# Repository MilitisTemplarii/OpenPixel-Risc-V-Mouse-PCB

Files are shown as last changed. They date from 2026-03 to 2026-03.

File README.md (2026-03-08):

# OpenPixel-Risc-V-Mouse-PCB
Risc-V (CH32V305) based PCB for high-end gaming mouse
0001-0140-ezgif com-optimize
RiscV_pcb_render
RiscV_pcb2_render

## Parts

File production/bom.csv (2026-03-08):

Designator | Footprint | Quantity | Value | LCSC Part #
BOOT1, SW_DPI1 | SW_SPST_TL3342 | 2 | SW_SPST
C1 | 0805 | 1 | 470pF
C10, C12, C9 | 0805 | 3 | 10uF
C11, C13, C15, C16, C17, C18, C19, C20, C22, C6, C7, C8 | 0805 | 12 | 100nF
C14, C21, C5 | 0805 | 3 | 22uF
C2 | 0805 | 1 | 2.2uF
C3, C4 | 0805 | 2 | 1uF
J1 | PinHeader_1x04_P2.00mm_Vertical | 1 | Conn_01x04_Pin
LED_DPI1 | LED_RGB_1210 | 1 | LED_BGRK
PAW3395 | PAW3395_LGA16_fixed | 1 | S1
POLLING1 | SSSS213202_AAL | 1 | SSSS213202
R4 | 0805 | 1 | 5,6K
R5 | 0805 | 1 | 100
R6 | 0805 | 1 | 330
R7 | 0805 | 1 | 220
R8 | 0805 | 1 | 10K
R9 | 0805 | 1 | 1K
RST1 | SW_SPST_EVQP7C | 1 | SW_SPST
SW_LAT1 | JST_SH_SM03B-SRSS-TB_1x03-1MP_P1.00mm_Horizontal | 1 | Conn_01x03_Pin
SW_LEFT1, SW_RGTH1, SW_WHEEL1 | SW_D2FC_OMR | 3 | SW_SPDT_321
U1 | SOT-23-5 | 1 | TLV70019_SOT23-5
U2 | SOT-23-5 | 1 | MIC5219-3.3YM5
U3 | LQFP-64_10x10mm_P0.5mm | 1 | CH32V30xRxTx
U4, U5, U6 | Texas_DRT-3 | 3 | TPD2EUSB30
USB1 | JST_PH_S5B-PH-K_1x05_P2.00mm_Horizontal | 1 | Conn_01x05_Pin
WHEEL_ENCODER1 | Encoder_Kailh_Wheel_3Pin | 1 | RotaryEncoder
Y1 | Oscillator_SMD_SeikoEpson_SG210-4Pin_2.5x2.0mm | 1 | 8MHZ_CMOS

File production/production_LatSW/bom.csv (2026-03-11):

Designator | Footprint | Quantity | Value | LCSC Part #
J1 | PinHeader_1x03_P1.00mm_Vertical | 1 | Conn_01x03
SW1, SW2 | SW_D2FC_OMR | 2 | D2FC-F-7N100M

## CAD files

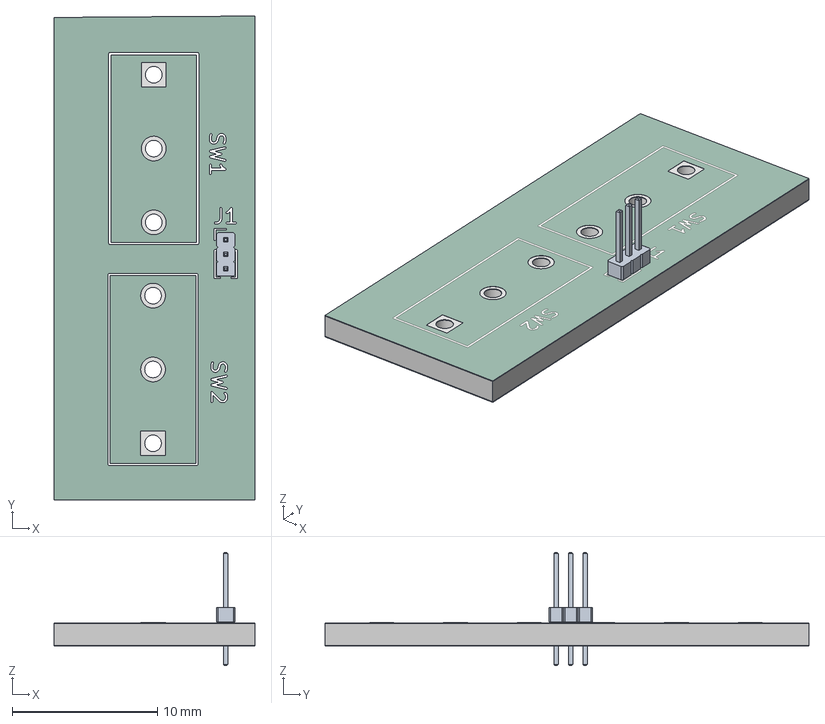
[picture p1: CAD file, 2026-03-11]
KiCad/RiscV_Mouse_LatSW.step
13.8 x 33.3 x 7.80 mm
PinHeader_1x03_P1.00mm_Vertical
RiscV_Mouse_LatSW_copper
RiscV_Mouse_LatSW_pad
RiscV_Mouse_LatSW_silkscreen
RiscV_Mouse_LatSW_soldermask x 2
RiscV_Mouse_LatSW_PCB

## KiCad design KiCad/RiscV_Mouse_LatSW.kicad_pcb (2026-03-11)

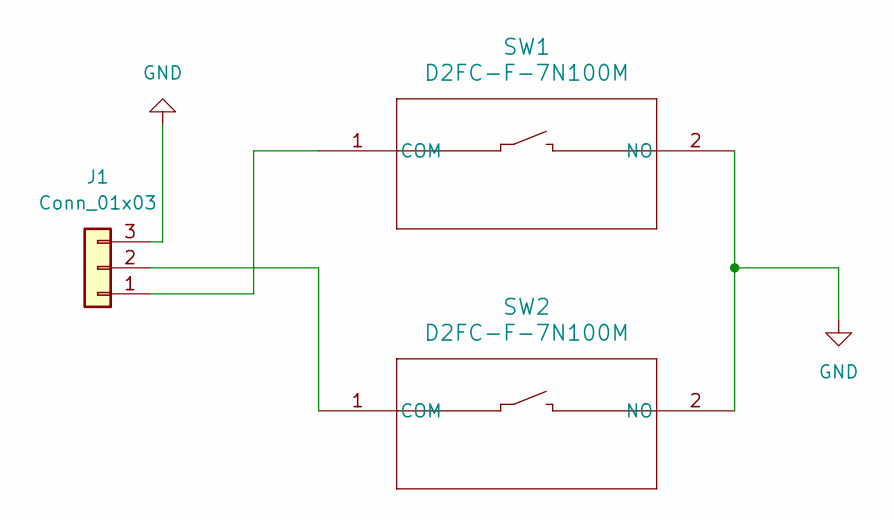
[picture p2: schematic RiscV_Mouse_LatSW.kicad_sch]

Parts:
J1: Conn_01x03; PinHeader_1x03_P1.00mm_Vertical
SW1, SW2: D2FC-F-7N100M; SW_D2FC_OMR

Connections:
GND: J1.3, SW1.2 (NO), SW2.2 (NO)
unnamed: J1.1, SW1.1 (COM)
unnamed: J1.2, SW2.1 (COM)

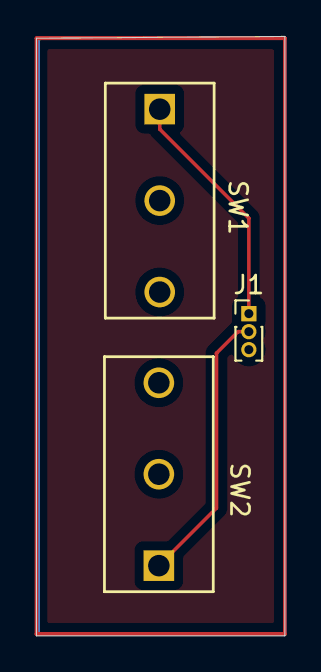
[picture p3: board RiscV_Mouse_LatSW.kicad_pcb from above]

Board: 2 copper layers, 13.8 x 33.3 mm, 3 parts (0 on the bottom side), 3 nets.

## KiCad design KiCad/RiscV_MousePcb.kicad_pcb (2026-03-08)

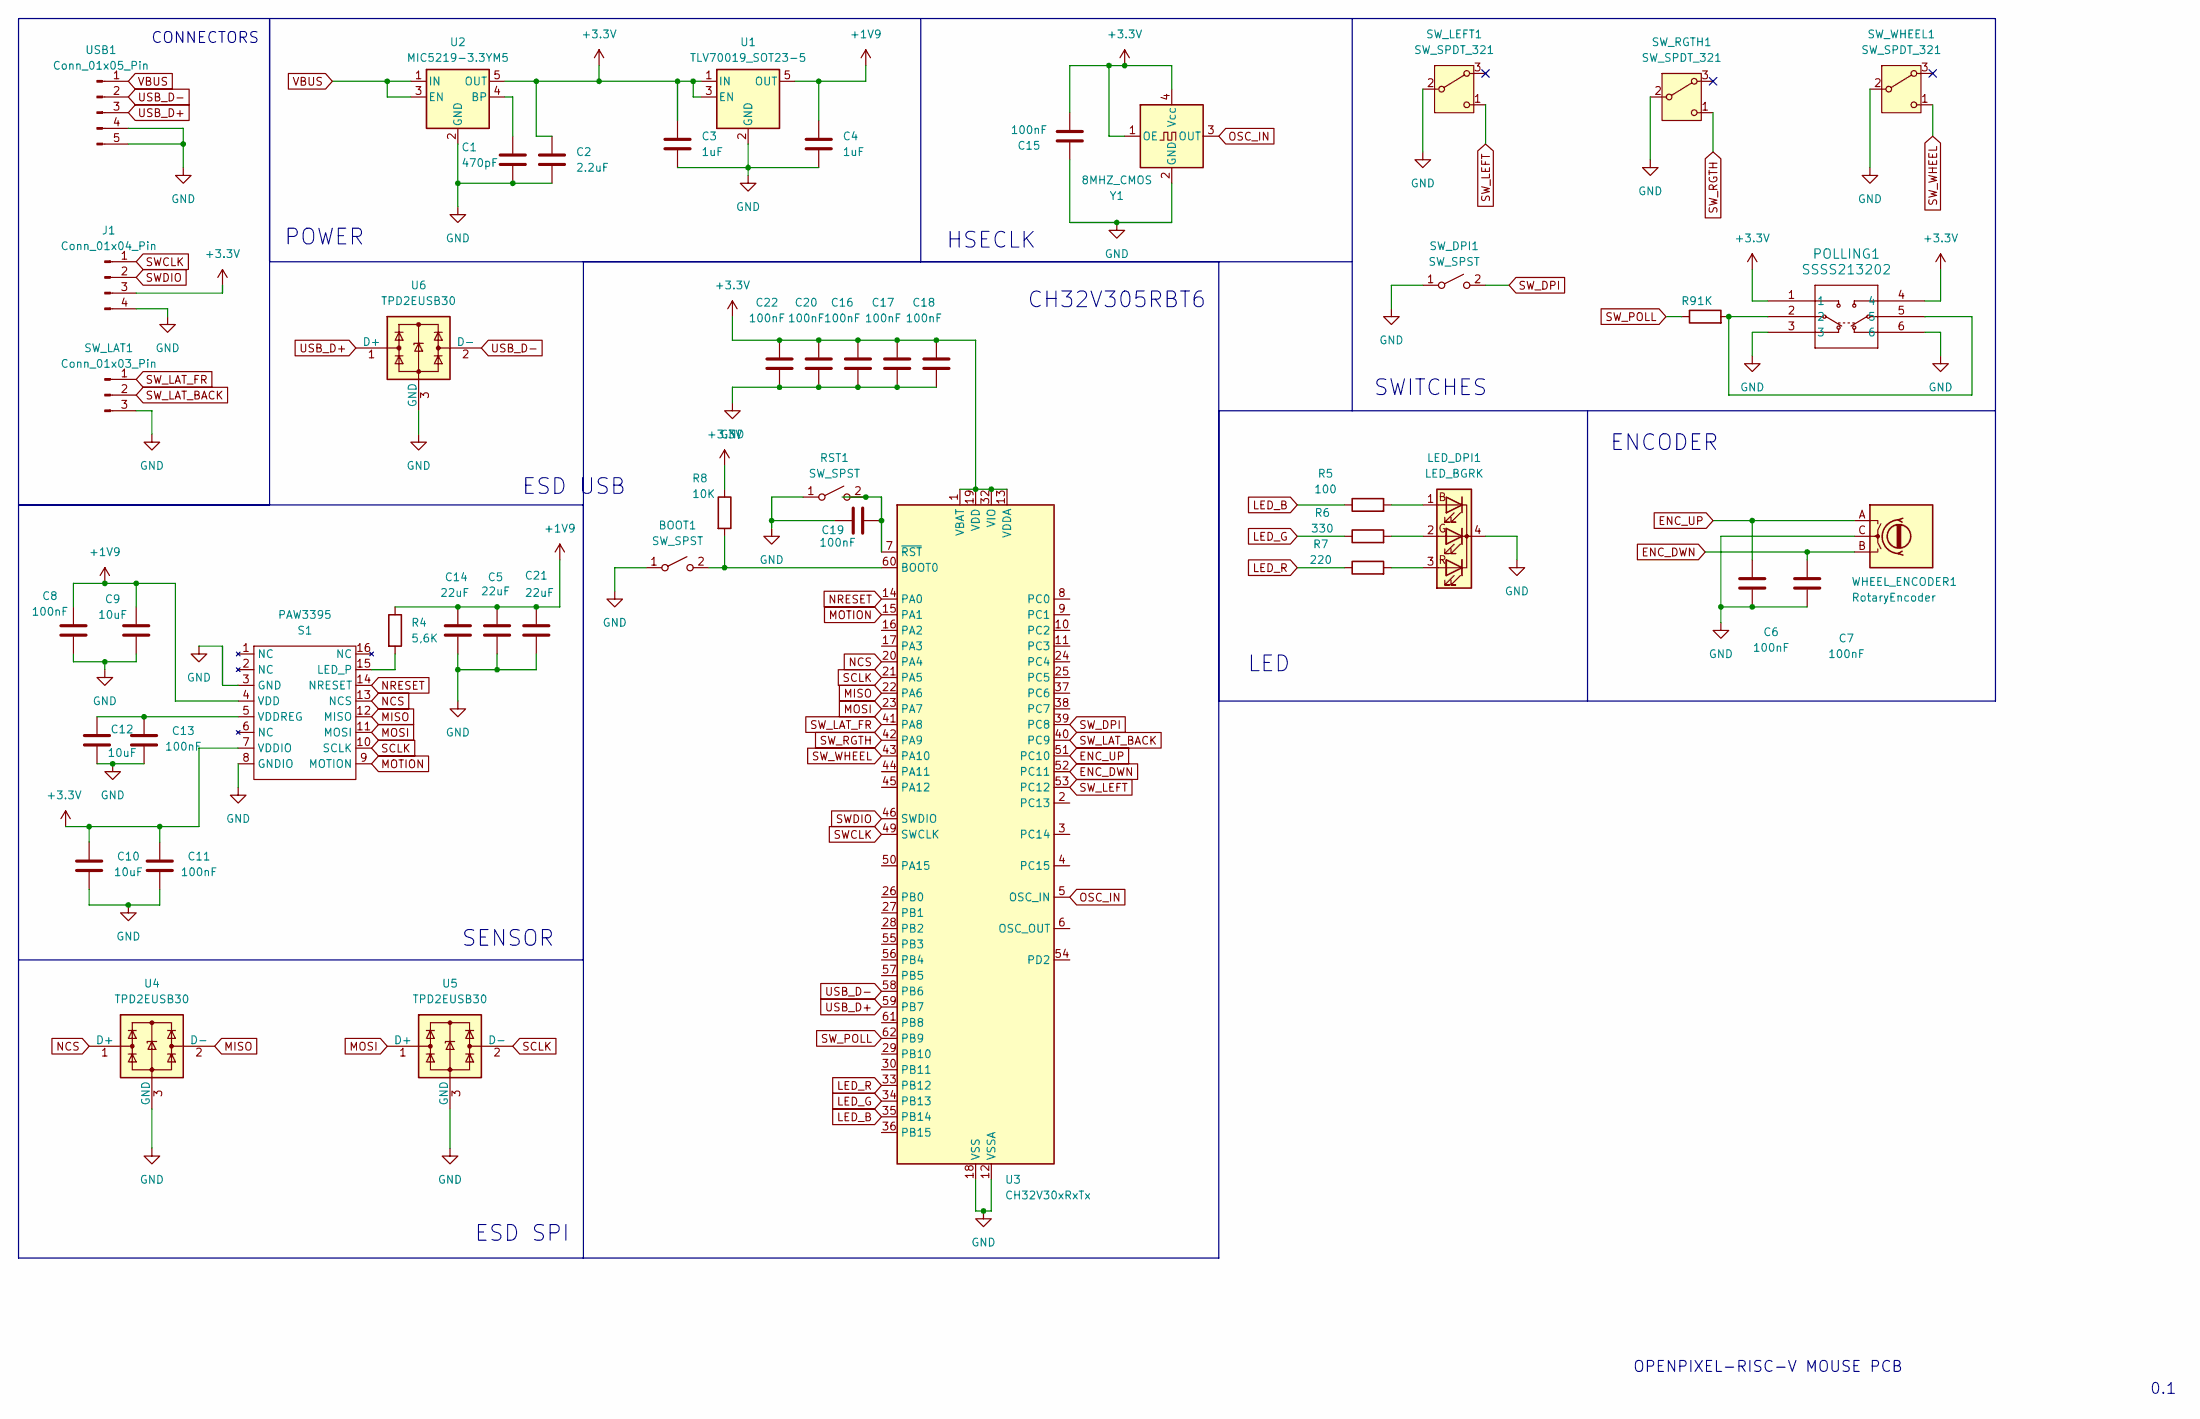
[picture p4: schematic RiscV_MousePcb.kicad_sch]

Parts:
BOOT1: SW_SPST; SW_SPST_TL3342
C1: 470pF; C_0805_2012Metric_Pad1.18x1.45mm_HandSolder
C2: 2.2uF; C_0805_2012Metric_Pad1.18x1.45mm_HandSolder
C3, C4: 1uF; C_0805_2012Metric_Pad1.18x1.45mm_HandSolder
C5, C14, C21: 22uF; C_0805_2012Metric_Pad1.18x1.45mm_HandSolder
C6, C7, C8, C11, C13, C15, C16, C17, C18, C19, C20, C22: 100nF; C_0805_2012Metric_Pad1.18x1.45mm_HandSolder
C9, C10, C12: 10uF; C_0805_2012Metric_Pad1.18x1.45mm_HandSolder
J1: Conn_01x04_Pin; PinHeader_1x04_P2.00mm_Vertical
LED_DPI1: LED_BGRK; LED_RGB_1210
PAW3395: S1; PAW3395_LGA16_fixed
POLLING1: SSSS213202; SSSS213202_AAL
R4: 5,6K; R_0805_2012Metric_Pad1.20x1.40mm_HandSolder
R5: 100; R_0805_2012Metric_Pad1.20x1.40mm_HandSolder
R6: 330; R_0805_2012Metric_Pad1.20x1.40mm_HandSolder
R7: 220; R_0805_2012Metric_Pad1.20x1.40mm_HandSolder
R8: 10K; R_0805_2012Metric_Pad1.20x1.40mm_HandSolder
R9: 1K; R_0805_2012Metric_Pad1.20x1.40mm_HandSolder
RST1: SW_SPST; SW_SPST_EVQP7C
SW_DPI1: SW_SPST; SW_SPST_TL3342
SW_LAT1: Conn_01x03_Pin; JST_SH_SM03B-SRSS-TB_1x03-1MP_P1.00mm_Horizontal
SW_LEFT1: SW_SPDT_321; SW_D2FC_OMR
SW_RGTH1: SW_SPDT_321; SW_D2FC_OMR
SW_WHEEL1: SW_SPDT_321; SW_D2FC_OMR
U1: TLV70019_SOT23-5; SOT-23-5
U2: MIC5219-3.3YM5; SOT-23-5
U3: CH32V30xRxTx; LQFP-64_10x10mm_P0.5mm
U4, U5, U6: TPD2EUSB30; Texas_DRT-3
USB1: Conn_01x05_Pin; JST_PH_S5B-PH-K_1x05_P2.00mm_Horizontal
WHEEL_ENCODER1: RotaryEncoder; Encoder_Kailh_Wheel_3Pin
Y1: 8MHZ_CMOS; Oscillator_SMD_SeikoEpson_SG210-4Pin_2.5x2.0mm

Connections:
+1V9: C4.1, C5.2, C8.1, C9.1, C14.2, C21.2, PAW3395.4 (VDD), R4.1, U1.5 (OUT)
+3.3V: C2.1, C3.1, C10.2, C11.2, C15.2, C16.1, C17.1, C18.1, C20.1, C22.1, J1.3, PAW3395.7 (VDDIO), POLLING1.1, POLLING1.4, R8.1, U1.1 (IN), U1.3 (EN), U2.5 (OUT), U3.1 (VBAT), U3.13 (VDDA), U3.19 (VDD), U3.32 (VIO), U3.48 (VDD), U3.64 (VIO), Y1.1 (OE), Y1.4 (Vcc)
ENC_DWN: C7.2, U3.52 (PC11), WHEEL_ENCODER1.B
ENC_UP: C6.2, U3.51 (PC10), WHEEL_ENCODER1.A
GND: BOOT1.1 (A), C1.2, C2.2, C3.2, C4.2, C5.1, C6.1, C7.1, C8.2, C9.2, C10.1, C11.1, C12.1, C13.1, C14.1, C15.1, C16.2, C17.2, C18.2, C19.1, C20.2, C21.1, C22.2, J1.4, LED_DPI1.4 (K), PAW3395.3 (GND), PAW3395.8 (GNDIO), POLLING1.3, POLLING1.6, RST1.1 (A), SW_DPI1.1 (A), SW_LAT1.3, SW_LEFT1.2 (B), SW_RGTH1.2 (B), SW_WHEEL1.2 (B), U1.2 (GND), U2.2 (GND), U3.12 (VSSA), U3.18 (VSS), U3.31 (VSS), U3.47 (VSS), U3.63 (VSS), U4.3 (GND), U5.3 (GND), U6.3 (GND), USB1.4, USB1.5, WHEEL_ENCODER1.C, Y1.2 (GND)
LED_B: R5.1, U3.35 (PB14)
LED_G: R6.1, U3.34 (PB13)
LED_R: R7.1, U3.33 (PB12)
MISO: PAW3395.12 (MISO), U3.22 (PA6), U4.2 (D-)
MOSI: PAW3395.11 (MOSI), U3.23 (PA7), U5.1 (D+)
MOTION: PAW3395.9 (MOTION), U3.15 (PA1)
NCS: PAW3395.13 (NCS), U3.20 (PA4), U4.1 (D+)
NRESET: PAW3395.14 (NRESET), U3.14 (PA0)
unnamed: BOOT1.2 (B), R8.2, U3.60 (BOOT0)
unnamed: LED_DPI1.1 (BA), R5.2
unnamed: LED_DPI1.2 (GA), R6.2
unnamed: LED_DPI1.3 (RA), R7.2
unnamed: PAW3395.15 (LED_P), R4.2
unnamed: C12.2, C13.2, PAW3395.5 (VDDREG)
unnamed: POLLING1.2, POLLING1.5, R9.2
unnamed: C19.2, RST1.2 (B), U3.7 (~RST)
unnamed: C1.1, U2.4 (BP)
OSC_IN: U3.5 (OSC_IN), Y1.3 (OUT)
SCLK: PAW3395.10 (SCLK), U3.21 (PA5), U5.2 (D-)
SWCLK: J1.1, U3.49 (SWCLK)
SWDIO: J1.2, U3.46 (SWDIO)
SW_DPI: SW_DPI1.2 (B), U3.39 (PC8)
SW_LAT_BACK: SW_LAT1.2, U3.40 (PC9)
SW_LAT_FR: SW_LAT1.1, U3.41 (PA8)
SW_LEFT: SW_LEFT1.1 (C), U3.53 (PC12)
SW_POLL: R9.1, U3.62 (PB9)
SW_RGTH: SW_RGTH1.1 (C), U3.42 (PA9)
SW_WHEEL: SW_WHEEL1.1 (C), U3.43 (PA10)
USB_D+: U3.59 (PB7), U6.1 (D+), USB1.3
USB_D-: U3.58 (PB6), U6.2 (D-), USB1.2
VBUS: U2.1 (IN), U2.3 (EN), USB1.1

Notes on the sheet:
LED
OPENPIXEL-RISC-V MOUSE PCB
0.1
SENSOR
CH32V305RBT6
ESD SPI
POWER
ENCODER
HSECLK
SWITCHES
CONNECTORS
ESD USB

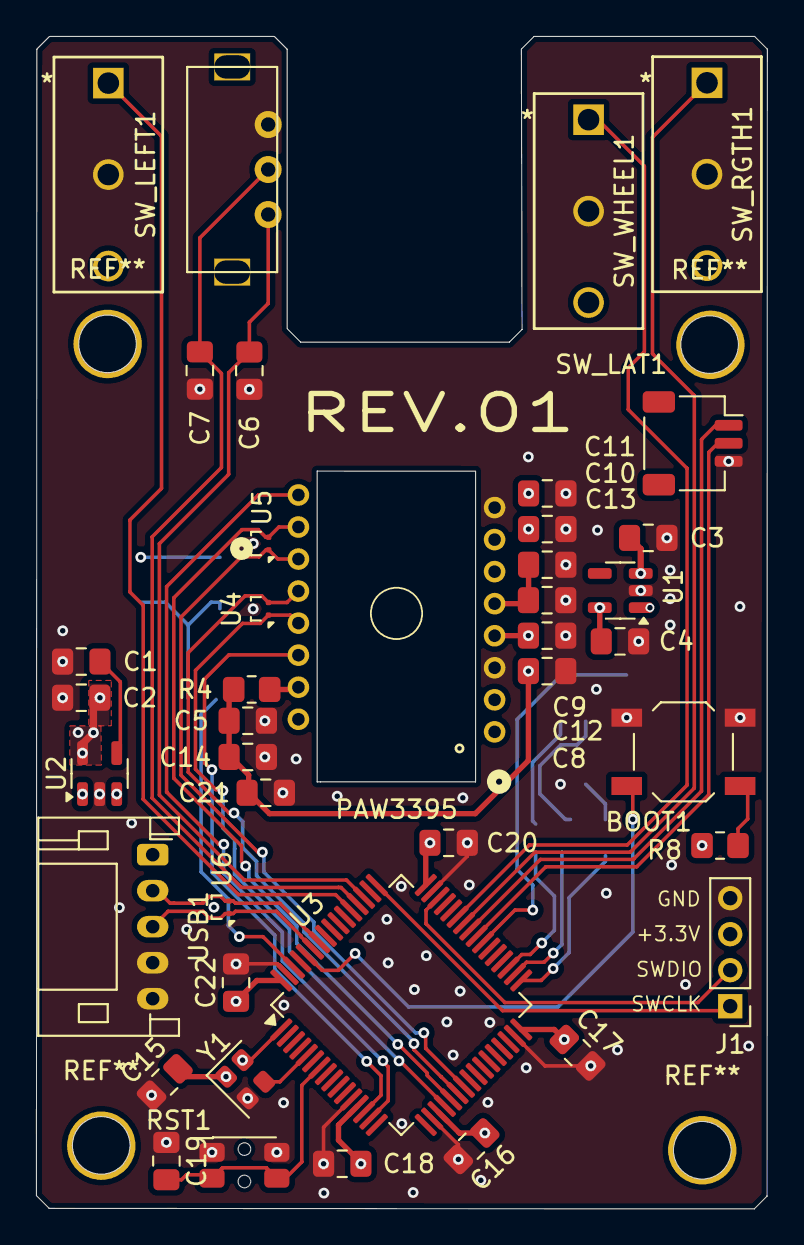
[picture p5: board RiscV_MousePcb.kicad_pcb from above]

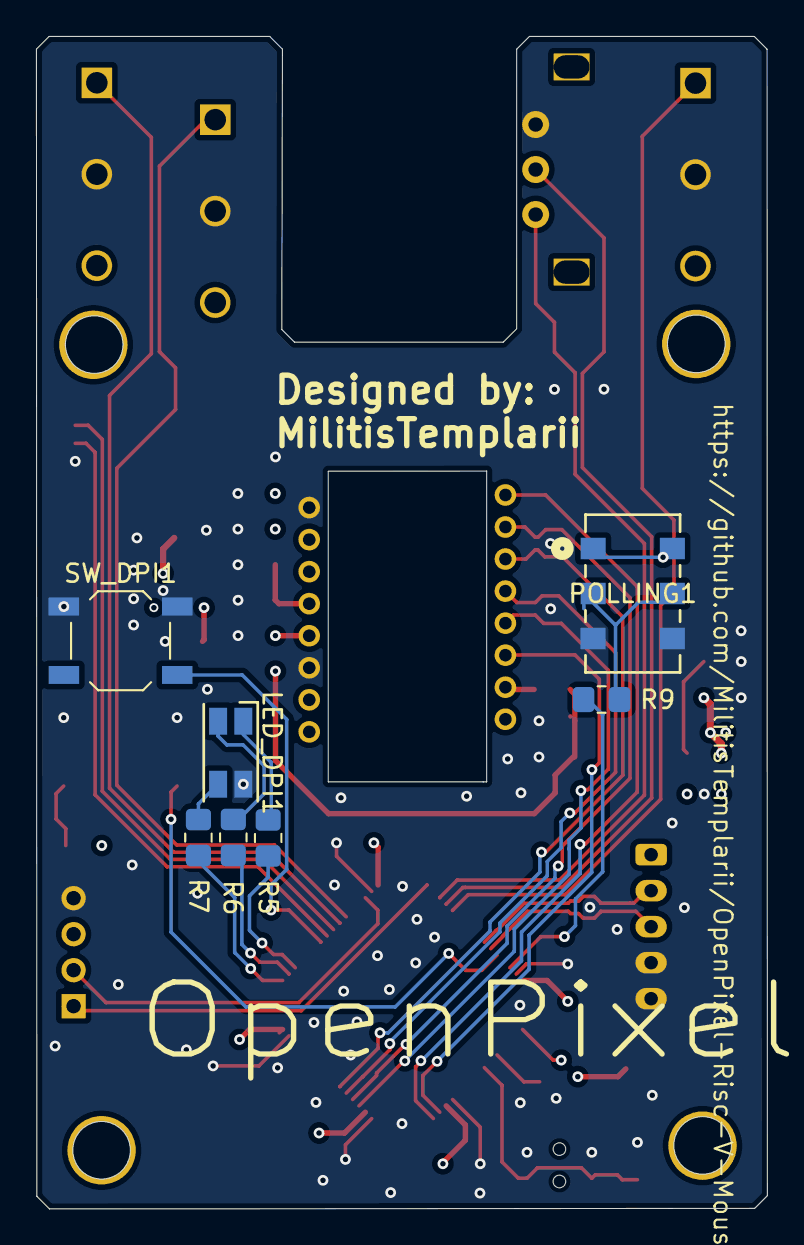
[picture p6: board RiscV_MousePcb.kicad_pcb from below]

Board: 4 copper layers, 40.6 x 65.1 mm, 48 parts (7 on the bottom side), 36 nets.
